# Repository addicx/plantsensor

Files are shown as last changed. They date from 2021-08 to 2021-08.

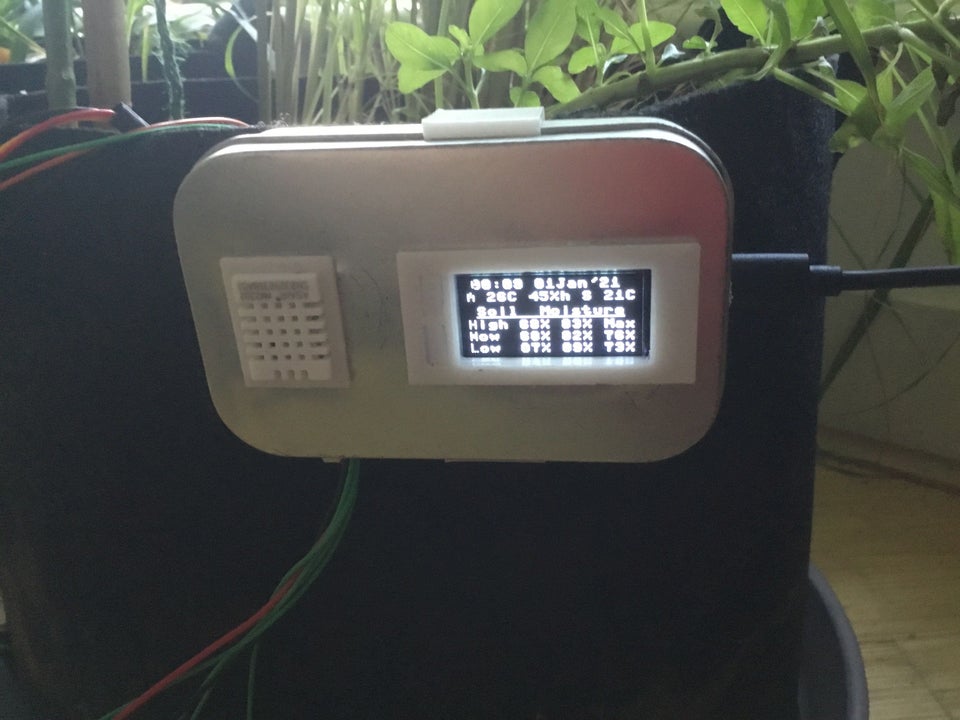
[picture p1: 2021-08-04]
Photo.jpg

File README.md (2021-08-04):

# plantsensor
A Raspberry Pi Pico plant sensor hub coded in Micropython

I used:
1x Raspberry Pi Pico - microcontroller
1x Waveshare Pico OLED 1.3 - screen for displaying values
1x DHT22 with 10kOhm resistor - air temperature and humidity sensor
1x Thermistor with 10kOhm resistor - for soil temperature
3x Capacitive soil moisture sensor V2.0s - for soil moisture detection
Wires
Heatshrinks
Holder
Nail varnish - for waterproofing soil sensors
Electrical tape - for waterproofing soil sensors
1 Altoid sized tin that I had lying about

DHT22 data pin was linked to the 3V by the resistor and wired to GP2
Thermistor data pin was linked to the 3V by the resistor and wired to GP16
Soil moisture sensors were wired to GP26, GP27 and GP28

All sensors were grounded to ground pins and powered by the 3V3O pin

You will need to add main.py, the src folder with CSMS.py and the Waveshare Pico OLED 1.3 driver on the Pico for this to run.
Thanks to ashleywm for the code to run the soil moisture sensors.

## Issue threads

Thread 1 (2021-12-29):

Calibration error

oxicottin, 2021-12-29:
I cant get calibration to work without the error below. line 7 in the cal example is csms.calibrate()

Traceback (most recent call last):
  File "<stdin>", line 7, in <module>
  File "CSMS.py", line 65, in calibrate
  File "CSMS.py", line 89, in read_raw
AttributeError: 'ADC' object has no attribute 'read'

SergeyMNet, 2023-04-14:
use self.adc.read_u16()

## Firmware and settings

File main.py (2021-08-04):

from machine import Pin,SPI,ADC #3v3 to humidity1, GP2 to humidity2 GND to humidity 4,  (Link DHT22 pins 1&2 with a 4.7K - 10K resistor)
import framebuf, onewire, ds18x20, rp2, time, random
from src.CSMS import CSMS

DC = 8
RST = 12
MOSI = 11
SCK = 10
CS = 9


class OLED_1inch3(framebuf.FrameBuffer):
    def __init__(self):
        self.width = 128
        self.height = 64
        
        self.cs = Pin(CS,Pin.OUT)
        self.rst = Pin(RST,Pin.OUT)
        
        self.cs(1)
        self.spi = SPI(1)
        self.spi = SPI(1,2000_000)
        self.spi = SPI(1,20000_000,polarity=0, phase=0,sck=Pin(SCK),mosi=Pin(MOSI),miso=None)
        self.dc = Pin(DC,Pin.OUT)
        self.dc(1)
        self.buffer = bytearray(self.height * self.width // 8)
        super().__init__(self.buffer, self.width, self.height, framebuf.MONO_HMSB)
        self.init_display()
        
        self.white =   0xffff
        self.black =   0x0000
        
    def write_cmd(self, cmd):
        self.cs(1)
        self.dc(0)
        self.cs(0)
        self.spi.write(bytearray([cmd]))
        self.cs(1)

    def write_data(self, buf):
        self.cs(1)
        self.dc(1)
        self.cs(0)
        self.spi.write(bytearray([buf]))
        self.cs(1)

    def init_display(self):
        """Initialize dispaly"""  
        self.rst(1)
        time.sleep(0.001)
        self.rst(0)
        time.sleep(0.01)
        self.rst(1)
        
        self.write_cmd(0xAE)#turn off OLED display

        self.write_cmd(0x00)   #set lower column address
        self.write_cmd(0x10)   #set higher column address 

        self.write_cmd(0xB0)   #set page address 
      
        self.write_cmd(0xdc)    #et display start line 
        self.write_cmd(0x00) 
        self.write_cmd(0x81)    #contract control 
        self.write_cmd(0x6f)    #128
        self.write_cmd(0x21)    # Set Memory addressing mode (0x20/0x21) #
    
        self.write_cmd(0xa0)    #set segment remap 
        self.write_cmd(0xc0)    #Com scan direction
        self.write_cmd(0xa4)   #Disable Entire Display On (0xA4/0xA5) 

        self.write_cmd(0xa6)    #normal / reverse
        self.write_cmd(0xa8)    #multiplex ratio 
        self.write_cmd(0x3f)    #duty = 1/64
  
        self.write_cmd(0xd3)    #set display offset 
        self.write_cmd(0x60)

        self.write_cmd(0xd5)    #set osc division 
        self.write_cmd(0x41)
    
        self.write_cmd(0xd9)    #set pre-charge period
        self.write_cmd(0x22)   

        self.write_cmd(0xdb)    #set vcomh 
        self.write_cmd(0x35)  
    
        self.write_cmd(0xad)    #set charge pump enable 
        self.write_cmd(0x8a)    #Set DC-DC enable (a=0:disable; a=1:enable)
        self.write_cmd(0XAF)
    def show(self):
        self.write_cmd(0xb0)
        for page in range(0,64):
            self.column = 63 - page              
            self.write_cmd(0x00 + (self.column & 0x0f))
            self.write_cmd(0x10 + (self.column >> 4))
            for num in range(0,16):
                self.write_data(self.buffer[page*16+num])

# Sensors
    #Onboard Temp
sensor_temp = machine.ADC(4)
conversion_factor = 3.3 / (65535)
reading = sensor_temp.read_u16() * conversion_factor
temperature = 27 - (reading - 0.706)/0.001721
    #External Temp
ds_pin = machine.Pin(16) #GP16 to central pin, 3v3_O to rightmost pin facing the flat side, GND to leftmost pin
ds_sensor = ds18x20.DS18X20(onewire.OneWire(ds_pin))
roms = ds_sensor.scan()

#Soil Moisture (CSMS)
adc0 = machine.ADC(machine.Pin(26)) #CA changed pin to 26 (ADC pins on a Pico are 26, 27 & 28)
adc1 = machine.ADC(machine.Pin(27)) #CA changed pin to 26 (ADC pins on a Pico are 26, 27 & 28)
adc2 = machine.ADC(machine.Pin(28)) #CA changed pin to 26 (ADC pins on a Pico are 26, 27 & 28)

csms0 = CSMS(adc0, min_value=60000, max_value=24854)
csms1 = CSMS(adc1, min_value=60000, max_value=24854)
csms2 = CSMS(adc2, min_value=60000, max_value=24854)

#Humidity
dht = ""
@rp2.asm_pio(set_init=(rp2.PIO.OUT_LOW,rp2.PIO.OUT_LOW),#Pico pin GP2 to DHT22 pin 2 facing the grid, Pico GND to DHT22 pin 4, Pico 3v3_O to DHT22 pin 1 (Link DHT22 pins 1&2 with a 4.7K - 10K resistor)
         autopush=True, in_shiftdir=rp2.PIO.SHIFT_LEFT)
def dht22():
    wrap_target()
    label("again")
    pull(block)
    set(pins, 0)
    mov(x, osr)
    label("loop1")
    jmp(x_dec, "loop1")
    set(pindirs, 0)
    wait(1, pin, 0)
    wait(0, pin, 0)
    wait(1, pin, 0)
    wait(0, pin, 0)
    set(y, 31)
    label("bits")
    wait(1, pin, 0) [25]
    in_(pins, 1)
    wait(0, pin, 0)
    jmp(y_dec, "bits")
      
    set(y, 7)
    label("check")
    wait(1, pin, 0)[25]
    set(pins,2)
    set(pins,0)
    in_(pins, 1)
    wait(0, pin, 0)
    jmp(y_dec, "check")
    push(block)
    wrap()
class DHT22():
    def __init__(self, gpio):
        self.sm = rp2.StateMachine(0, dht22, freq=490196,
            in_base=Pin(gpio), set_base=Pin(gpio),
                                        jmp_pin=Pin(gpio))
        self.sm.active(1)
    def getReading(self):
        self.sm.put(500)
        data=0
        data = self.sm.get()
        byte1 = (data >> 24 & 0xFF)
        byte2 = (data >> 16 & 0xFF)
        byte3 = (data >> 8 & 0xFF)
        byte4 = (data & 0xFF)
        checksum = self.sm.get() & 0xFF
        self.checksum = (checksum == (byte1+byte2+byte3+byte4) & 0xFF)
        self.humidity = ((byte1 << 8) | byte2) / 10.0
        neg = byte3 & 0x80
        byte3 = byte3 & 0x7F
        self.temperature = (byte3 << 8 | byte4) / 10.0
        if neg > 0:
            self.temperature = -self.temperature

# Definitions
i = 0
months = ["Jan", "Feb", "Mar", "Apr", "May", "Jun", "Jul", "Aug", "Sep", "Oct", "Nov", "Dec"]

while True:

    filename = ("data" + str(random.getrandbits(16)) + ".csv") #log given a random name to minimise risk of overwriting data upon power loss
    file = open(filename, "w")
    file.close()

    #It begins
    while True:
        #empty cache and assess memory strain
        csvdata = []
        with open(filename,'r') as file:
            for line in file:
                csvdata.append(line.rstrip('\n').rstrip('\r').split(','))
        if len(csvdata) > 300:
            break
        #set time parameters
        t_end = time.time() + 60 #time ~between reads - 3600 in final
        
            #zfill date parameters
        if len(str(abs(time.localtime()[4]))) == 1:
            zmin = ("0" + str(abs(time.localtime()[4])))
        else:
            zmin = str(abs(time.localtime()[4]))
        if len(str(abs(time.localtime()[3]))) == 1:
            zhr = ("0" + str(abs(time.localtime()[3])))
        else:
            zhr = str(abs(time.localtime()[3]))
        if len(str(abs(time.localtime()[2]))) == 1:
            zday = ("0" + str(abs(time.localtime()[2])))
        else:
            zday = str(abs(time.localtime()[2]))

        date = (zhr + ":" + zmin + " " + zday + months[abs(time.localtime()[1])] + "'" + str(abs(time.localtime()[0]) % 100))
        #iterate lognum
        i += 1
        if len(str(i)) == 1:
            lognum = ("Log0000" + str(i))
        elif len(str(i)) == 2:
            lognum = ("Log000" + str(i))
        elif len(str(i)) == 3:
            lognum =  ("Log00" + str(i))
        elif len(str(i)) == 4:
            lognum =  ("Log0" + str(i))
        else:
            lognum =  ("Log" + str(i))
        # MinMax values
        sm1set = [x[5] for x in csvdata]
        sm2set = [x[6] for x in csvdata]
        sm3set = [x[7] for x in csvdata]
        csvdata = []
        if sm1set ==[]:
            row3 = "High " + "N/A" + " " + "N/A" + " " + "N/A"
            row5 = "Low  " + "N/A" + " " + "N/A" + " " + "N/A"
        else:
            row3 = "High " + max(sm1set) + " " + max(sm2set) + " " + max(sm3set)
            row5 = "Low  " + min(sm1set) + " " + min(sm2set) + " " + min(sm3set)
        sm1set = []
        sm2set = []
        sm3set = []
        #update sensors
        ds_sensor.convert_temp()
        time.sleep_ms(750) #need to wait 750 ms between convert and read
        for rom in roms:
            stemp = ds_sensor.read_temp(rom)
        if len(str(round(stemp))) ==1:
            zstemp = "0" + str(round(stemp))
        else:
            zstemp = str(round(stemp))
        dht = DHT22(2)
        dht.getReading()
        sensor_temp = machine.ADC(4)
        conversion_factor = 3.3 / (65535)
        reading = sensor_temp.read_u16() * conversion_factor
        temperature = 27 - (reading - 0.706)/0.001721
        soilz1 = csms0.read(25)
        soilz2 = csms1.read(25)
        soilz3 = csms2.read(25)
        if len(str(soilz1)) == 1:#normalises the length of the values
            soil1 = ("0" + str(soilz1) + "%")
        elif len(str(soilz1)) == 2:
            soil1 = (str(soilz1) + "%")
        else:
            soil1 = ("Max")
        if len(str(soilz2)) == 1:#normalises the length of the values
            soil2 = ("0" + str(soilz2) + "%")
        elif len(str(soilz2)) == 2:
            soil2 = (str(soilz2) + "%")
        else:
            soil2 = ("Max")
        if len(str(soilz3)) == 1:#normalises the length of the values
            soil3 = ("0" + str(soilz3) + "%")
        elif len(str(soilz1)) == 2:
            soil3 = (str(soilz3) + "%")
        else:
            soil3 = ("Max")
        if len(str(round(dht.temperature))) ==1:
            ztemp = "0" + str(round(dht.temperature))
        else:
            ztemp = str(round(dht.temperature))
        if len(str(round(dht.humidity))) ==1:
            zhum = "0" + str(round(dht.humidity))
        else:
            zhum = str(round(dht.humidity))
        row0 = (date)
        row1 = "A " + ztemp + "C " + zhum + "%h S " + zstemp + "C"
        row2 = " Soil  Moisture "
        row4 = "Now  " + str(soil1) + " " + str(soil2) + " " + str(soil3)
            #write to screen
        OLED = OLED_1inch3() #Fills the screen with the defined row strings
        OLED.fill(0x0000)
        OLED.text(row0,6,1)
        OLED.text(row1,1,11)
        OLED.text(row2,1,23)
        OLED.line(9,31,120,31,OLED.white)
        OLED.text(row3,1,34)
        OLED.text(row4,1,44)
        OLED.text(row5,1,54)
        OLED.show()
        #write to log
        file = open(filename, "a+")
        file.write(str(lognum) + "," + str(time.time()) + "," + str(dht.temperature) + "," + str(dht.humidity) + "," + str(stemp) + "," + str(soil1) + "," + str(soil2) + "," + str(soil3) + "\n")
        file.close()
        #buttons
        keyA = Pin(15,Pin.IN,Pin.PULL_UP)
        keyB = Pin(17,Pin.IN,Pin.PULL_UP)
        
        import micropython
        micropython.mem_info()#memory check DEBUG
        
        keyA = Pin(15,Pin.IN,Pin.PULL_UP)
        keyB = Pin(17,Pin.IN,Pin.PULL_UP)
        with open(filename,'r') as file:
            for line in file:
                csvdata.append(line.rstrip('\n').rstrip('\r').split(','))
        t_end = time.time() + 60
        activeline = len(csvdata)
        numlines = len(csvdata)
        while time.time() < t_end:

            if keyA.value() == 0:
                OLED.fill(0x0000)
                OLED.text(str(csvdata[activeline-1][0]),1,1)
                OLED.line(9,11,120,11,OLED.white)
                OLED.text("Air Temp: " + str(csvdata[activeline-1][2]) + "C",1,14)
                OLED.text("Humidity: " + str(csvdata[activeline-1][3]) + "%",1,24)
                OLED.text("Soil Temp: " + str(csvdata[activeline-1][4]) + "C",1,34)
                OLED.text("CSMS:" + str(csvdata[activeline-1][5]) + " " + str(csvdata[activeline-1][6]) + " " + str(csvdata[activeline-1][7]),1,44)
                OLED.text(str(time.time() - t_end),1,54)
                OLED.show()
                activeline += 1
                if activeline > numlines:
                    csvdata = []
                    break
              
                
            if keyB.value() == 0:
                OLED.fill(0x0000)
                OLED.text(str(csvdata[activeline-1][0]),1,1)
                OLED.line(9,11,120,11,OLED.white)
                OLED.text("Air Temp: " + str(csvdata[activeline-1][2]) + "C",1,14)
                OLED.text("Humidity: " + str(csvdata[activeline-1][3]) + "%",1,24)
                OLED.text("Soil Temp: " + str(csvdata[activeline-1][4]) + "C",1,34)
                OLED.text("CSMS:" + str(csvdata[activeline-1][5]) + " " + str(csvdata[activeline-1][6]) + " " + str(csvdata[activeline-1][7]),1,44)
                OLED.text(str(time.time() - t_end),1,54)
                OLED.show()
                activeline -= 1
                if activeline < 0:
                    activeline += 1

            OLED.show()

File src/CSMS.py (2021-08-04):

# Copyright(c) 2020 Ashley Morris
#
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
# This module reads values from Capacitative Soil Moisture Sensors.
#
# Before using the CSMS you must check the max input voltage of the ADC on your
# microcontroller, failure to do so may damage your IC.
#
# ESP32: 0v - 1.0v https://docs.micropython.org/en/latest/esp32/quickref.html#adc-analog-to-digital-conversion
# ESP8266: 0v - 3.6v https://docs.micropython.org/en/latest/esp8266/quickref.html#adc-analog-to-digital-conversion
#
# To use this module, you must first run the calibration. The calibration must be ran
# using the minimum and maximum envrionments your sensor is going to run in. For example
# in air and then in water for the maximum. The calibration function gives you 10 seconds
# to insert your sensor into the min/max environments.
#
# The function will then return the calibrated values.
#
# See calibration_example.py and example.py


from machine import ADC, Pin
import time


class CSMS:

    def __init__(self, adc, min_value=None, max_value=None):
        self.calibrated_min = min_value
        self.calibrated_max = max_value
        self.adc = adc

        if self.calibrated_min is None or self.calibrated_max is None:
            print("Calibrated min/max values not set. Run calibration.")
            return

    # Calibration reads the ADC value from the sensor 100 times and returns an average
    def calibrate(self):
        min_value = None
        max_value = None
        iterations = 100

        print('Calibrate sensor for the minimum environment, for example in air.')
        print('Calibration will start in 10 seconds.')
        time.sleep(10)
        print('Starting minimum calibration')

        min_value = self.read_raw(iterations)

        print('Minimum calibration complete')
        time.sleep(2)
        print('Calibrate sensor for the maximum environment, for example in water')
        print('Calibration will start in 10 seconds.')
        time.sleep(10)
        print('Starting maximum calibration')

        max_value = self.read_raw(iterations)

        print('Maximum calibration complete')
        time.sleep(2)
        print('Calibration complete! Modify your programs variables with the following results:')

        print('min_value = ', round(min_value))
        print('max_value = ', round(max_value))

    # Reads from the ADC for x number of times and then returns the average from all the readings
    # By default read the ADC 25 times with a 100ms pause between readings, this returns a more accurate reading.
    def read_raw(self, iterations):
        readings = []

        while len(readings) < iterations:
            reading = self.adc.read()
            readings.append(reading)
            time.sleep_ms(100)

        return sum(readings) / len(readings)

    # Convert the averaged or single reading to percentage between calibrated min and max values
    def convert_to_percentage(self, reading):
        percent = ((reading - self.calibrated_min) /
                   (self.calibrated_max - self.calibrated_min)) * 100

        # If the percentage returned is lower or higher than the calibrated min/max then return 0%/100% with a warning
        if percent < 0:
            print('Value less than 0%, check calibration')
            return 0

        if percent > 100:
            print('Value greater than 100%, check calibration')
            return 100

        return percent

    # Read the ADC and return the result in percentage
    def read(self, iterations=25):
        reading = self.read_raw(iterations)
        return round(self.convert_to_percentage(reading))

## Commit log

2021-08-04 Create main.py
    This is the script that runs everything. If you don't want it to run automatically, rename it. It requires src.CSMS and the Waveshare Pico OLED 1.3 driver to run.
2021-08-04 Added a concept image and Fritzing wiring diagram
    [Plant sensor 1.0.fzz]
2021-08-04 Create CSMS.py
    This code is needed to run the soil moisture sensors. It was copied in its entirety from ashleywm's repository under the terms of the included license.
2021-08-04 Create calibration_example.py
    Use this to get a calibration figure from your soil moisture sensors. Copied in its entirety from ashleywm's repository under the terms of the license found in src/csms.py
